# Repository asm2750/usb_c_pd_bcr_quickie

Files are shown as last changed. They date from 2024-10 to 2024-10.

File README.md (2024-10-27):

# USB-C PD Barrel Connector Replacement

A USB-C Power Delivery BCR Example Design:
* Based on example design from the CYPD 3177 Datasheet
* Configurable output voltage and current with resistors
* Header included for additional configuration

# WHY?
I needed a 9V wall wart for a device I recently acquired. Instead of buying another wall wart I wanted to leverage the many USB-C power supplies I have.

# Future Modifications
* Add a rotary switch for rapid voltage changes
* Add screw terminal option if micro-fit 3.0 connector is not available
* Design a 3D printable case
* Add proper BOM, v0.1 design was fabricated and assembled at JLCPCB

# License
Refer to the [License](LICENSE.md) for information.

# Tools Used
PCB - Kicad 8

# Fabricated Design
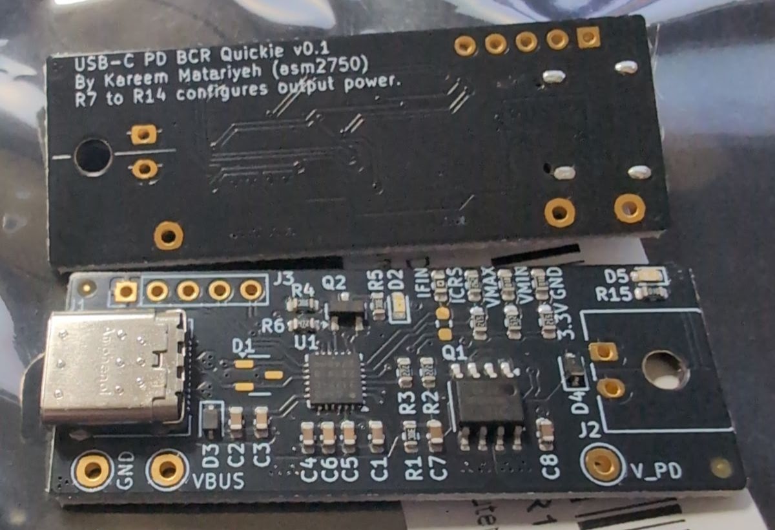
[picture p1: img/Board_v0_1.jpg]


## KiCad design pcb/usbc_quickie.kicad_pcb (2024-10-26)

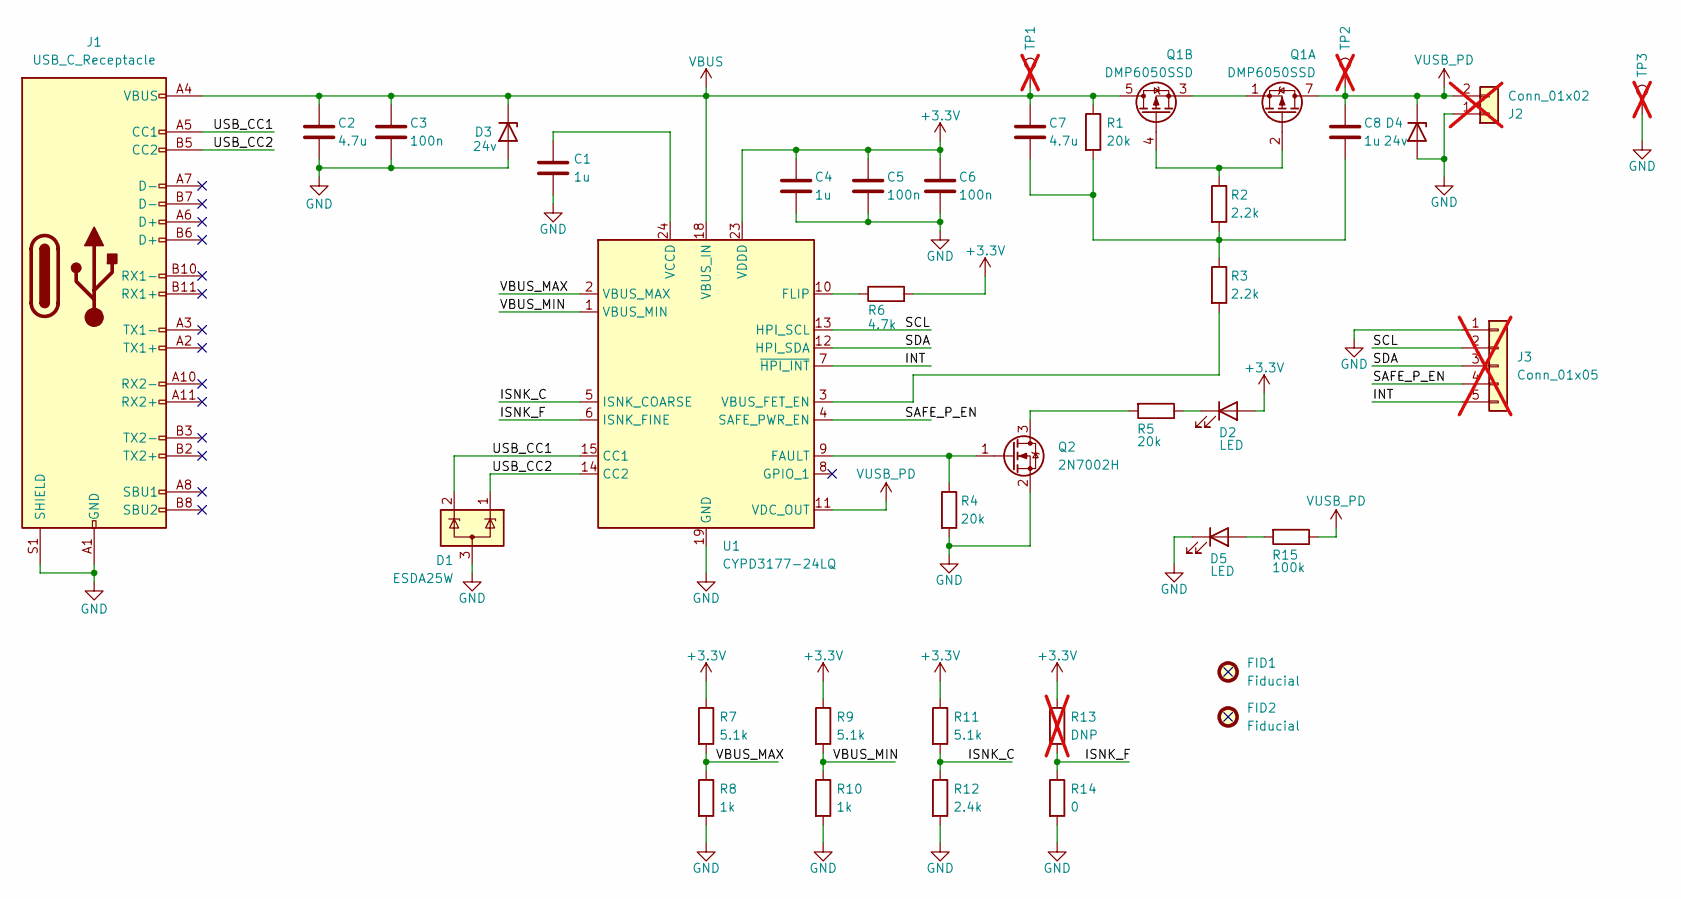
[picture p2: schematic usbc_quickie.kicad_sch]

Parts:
C1, C4, C8: 1u; C_0603_1608Metric; LCSC PN (Sub) C77046
C2, C7: 4.7u; C_0603_1608Metric; LCSC PN (Sub) C90057
C3, C5, C6: 100n; C_0603_1608Metric; LCSC PN (Sub) C354391
D1: ESDA25W; SOT-323_SC-70; LCSC PN (Sub) C3021136
D2: LED; LED_0603_1608Metric; LCSC PN (Sub) C510294
D3, D4: 24v; D_SOD-323; LCSC PN (Sub) C674401
D5: LED; LED_0603_1608Metric; LCSC PN (Sub) C3000897
FID1, FID2: Fiducial; Fiducial_0.5mm_Mask1.5mm
J1: USB_C_Receptacle; USB_C_Receptacle_Amphenol_12401610E4-2A; LCSC PN (Sub) C464604
J2: Conn_01x02; Molex_Micro-Fit_3.0_43650-0200_1x02_P3.00mm_Horizontal; not fitted
J3: Conn_01x05; PinHeader_1x05_P2.54mm_Vertical; not fitted
Q1: DMP6050SSD; SOIC-8_3.9x4.9mm_P1.27mm; LCSC PN (Sub) C531158
Q2: 2N7002H; SOT-23; LCSC PN (Sub) C672108
R1, R4, R5: 20k; R_0603_1608Metric; LCSC PN (Sub) C705889
R2, R3: 2.2k; R_0603_1608Metric; LCSC PN (Sub) C860297
R6: 4.7k; R_0603_1608Metric; LCSC PN (Sub) C705926
R7, R9, R11: 5.1k; R_0603_1608Metric_Pad0.98x0.95mm_HandSolder; LCSC PN (Sub) C860455
R8, R10: 1k; R_0603_1608Metric_Pad0.98x0.95mm_HandSolder; LCSC PN (Sub) C860716
R12: 2.4k; R_0603_1608Metric_Pad0.98x0.95mm_HandSolder; LCSC PN (Sub) C784582
R13: DNP; R_0603_1608Metric_Pad0.98x0.95mm_HandSolder; not fitted
R14: 0; R_0603_1608Metric_Pad0.98x0.95mm_HandSolder; LCSC PN (Sub) C116699
R15: 100k; R_0603_1608Metric; LCSC PN (Sub) C122538
TP1, TP2, TP3: TestPoint; Pin_D1.0mm_L10.0mm_LooseFit; not fitted
U1: CYPD3177-24LQ; QFN-24-1EP_4x4mm_P0.5mm_EP2.75x2.75mm; LCSC PN (Sub) C2959321

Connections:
+3.3V: C4.1, C5.1, C6.1, D2.2 (A), R6.2, R7.1, R9.1, R11.1, R13.1, U1.23 (VDDD)
/INT: J3.5, U1.7 (~HPI_INT)
/ISNK_C: R11.2, R12.1, U1.5 (ISNK_COARSE)
/ISNK_F: R13.2, R14.1, U1.6 (ISNK_FINE)
/SAFE_P_EN: J3.4, U1.4 (SAFE_PWR_EN)
/SCL: J3.2, U1.13 (HPI_SCL)
/SDA: J3.3, U1.12 (HPI_SDA)
/USB_CC1: D1.2 (K), J1.A5 (CC1), U1.15 (CC1)
/USB_CC2: D1.1 (K), J1.B5 (CC2), U1.14 (CC2)
/VBUS_MAX: R7.2, R8.1, U1.2 (VBUS_MAX)
/VBUS_MIN: R9.2, R10.1, U1.1 (VBUS_MIN)
GND: C1.2, C2.2, C3.2, C4.2, C5.2, C6.2, D1.3 (A), D3.2 (A), D4.2 (A), D5.1 (K), J1.A1 (GND), J1.A12 (GND), J1.B1 (GND), J1.B12 (GND), J1.S1 (SHIELD), J2.1, J3.1, Q2.2 (S), R4.2, R8.2, R10.2, R12.2, R14.2, TP3.1, U1.19 (GND), U1.22 (GND), U1.25 (GND)
unnamed: C7.2, C8.2, R1.2, R2.2, R3.1
unnamed: D2.1 (K), R5.1
unnamed: D5.2 (A), R15.2
unnamed: Q1.2 (G1), Q1.4 (G2), R2.1
unnamed: Q1.1 (S1), Q1.3 (S2)
unnamed: Q2.3 (D), R5.2
unnamed: Q2.1 (G), R4.1, U1.9 (FAULT)
unnamed: R6.1, U1.10 (FLIP)
unnamed: R3.2, U1.3 (VBUS_FET_EN)
unnamed: C1.1, U1.24 (VCCD)
VBUS: C2.1, C3.1, C7.1, D3.1 (K), J1.A4 (VBUS), J1.A9 (VBUS), J1.B4 (VBUS), J1.B9 (VBUS), Q1.5 (D2), Q1.6 (D2), R1.1, TP1.1, U1.18 (VBUS_IN)
VUSB_PD: C8.1, D4.1 (K), J2.2, Q1.7 (D1), Q1.8 (D1), R15.1, TP2.1, U1.11 (VDC_OUT)

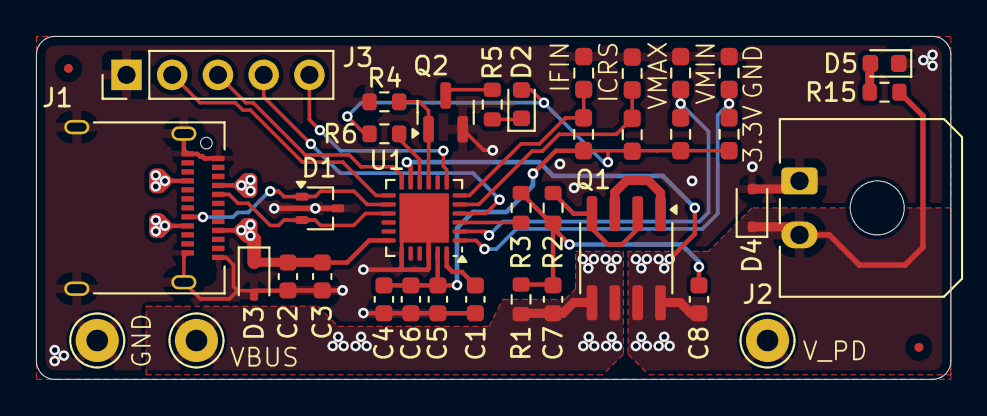
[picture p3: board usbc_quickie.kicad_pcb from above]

Board: 2 copper layers, 50.8 x 19.0 mm, 39 parts (0 on the bottom side), 24 nets.
